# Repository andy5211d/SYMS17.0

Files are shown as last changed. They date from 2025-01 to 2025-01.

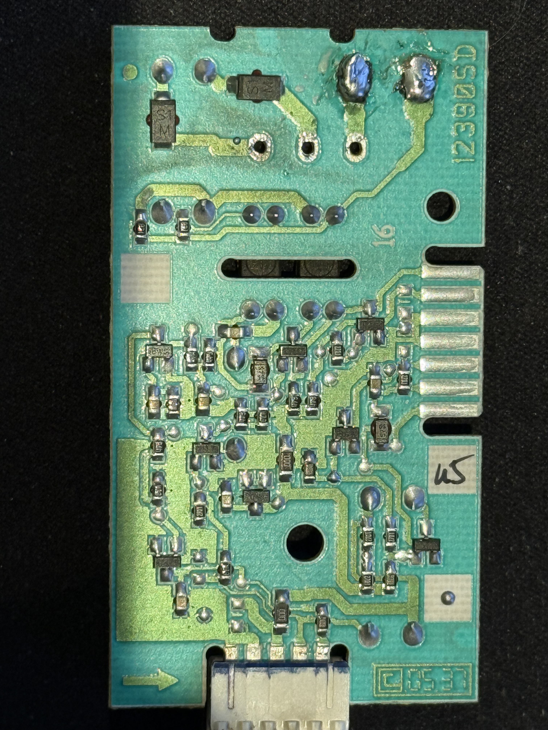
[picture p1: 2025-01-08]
pictures/230V Controls Track Side.JPG

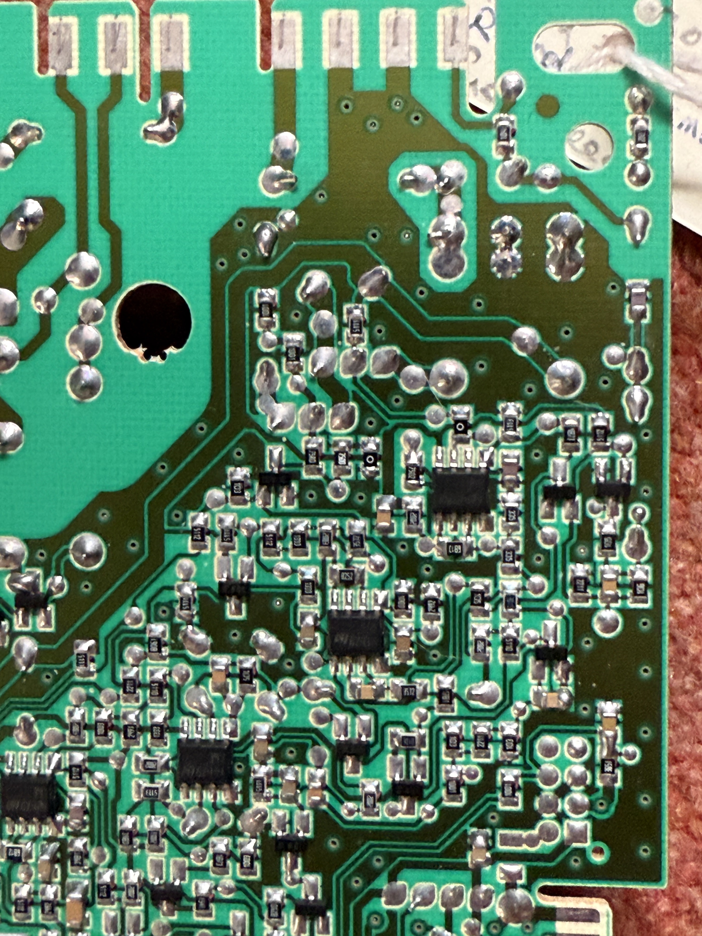
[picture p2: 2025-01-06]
pictures/IMG_2305.JPG

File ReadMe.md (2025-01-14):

The SYMS17.0 Control PCB (2000802731) used in a number of central heating and combi boilers.  This board has voltages that WILL KILL YOU if you touch the HV DC side.  

Included are details of some capacitors that may require changing if the board is faulty.  I change the five main capacitors as a matter of course.  A fault in the HV side (blown switcher) will often take out tracks and the through-hole plating. Usually not worth trying to repair.  Also included are some circuit details and relevant voltages around the PCB.  

Check your board as this is just my guess as to the details and circuit snippets!  

This is an unregulated SMPS, in that there is NO feedback between the secondary voltages and the switcher drive.  The main LV DC is around 40V with the boiler quiescent, (note the smoothing capacitors for this are 35V working!), and during operation drops to around 30V dependent upon fan speed.  The second LV DC is around 12V dropping to 9V dependent upon fan speed.  Two other voltages, 18V and 5V are used and these are from regulators and thus stable irrespective of the fan speed.  There are probably other derived voltages and thus regulators.  The opto coupler, U102, provides the controlling micro with the AC input (and perhaps HV DC value), or at least that's my assumption from tracing tracks on the board!

I have noticed at least three versions of the board (see number at the bottom left corner). As best I can tell variations are around the regulator U503, some boards seem to omit this and later boards this regulator has been designed out.

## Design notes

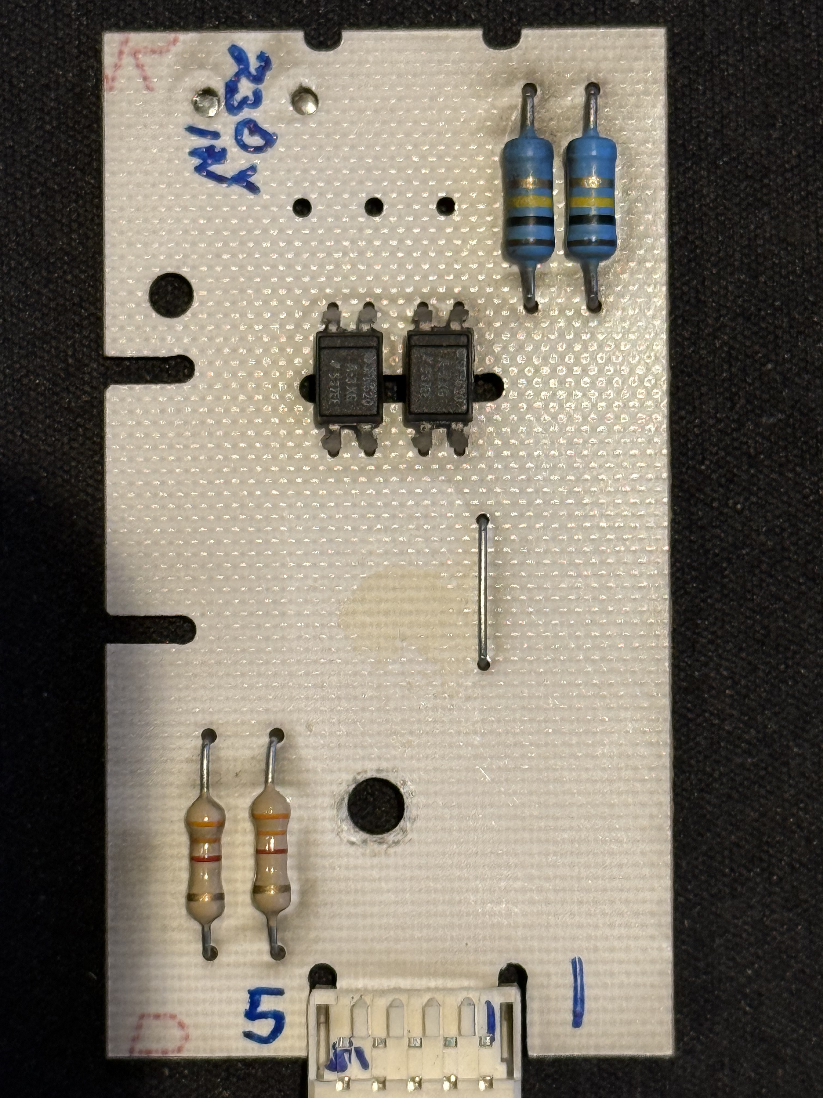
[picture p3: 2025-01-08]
pictures/230V Controls Comp Side.JPG

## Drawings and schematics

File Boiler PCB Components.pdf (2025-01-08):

# Glow Worm cxi, hxi & sxi PCB - Components

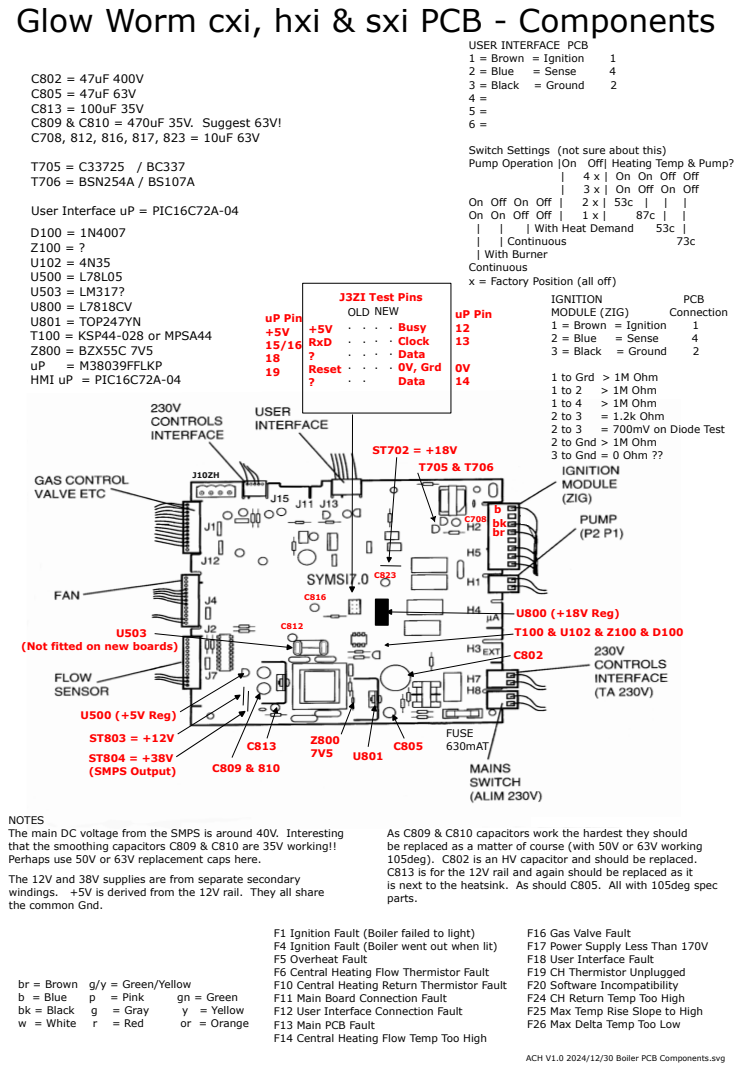
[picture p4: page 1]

Switch Settings (not sure about this)
Pump Operation |On Off| Heating Temp & Pump?

With Burner
Continuous
x = Factory Position (all off)

(Not fitted on new boards)

NOTES
The main DC voltage from the SMPS is around 40V. Interesting
that the smoothing capacitors C809 & C810 are 35V working!!
Perhaps use 50V or 63V replacement caps here.
The 12V and 38V supplies are from separate secondary
windings. +5V is derived from the 12V rail. They all share
the common Gnd.

As C809 & C810 capacitors work the hardest they should
be replaced as a matter of course (with 50V or 63V working
105deg). C802 is an HV capacitor and should be replaced.
C813 is for the 12V rail and again should be replaced as it
is next to the heatsink. As should C805. All with 105deg spec
parts.

F1 Ignition Fault (Boiler failed to light)
F4 Ignition Fault (Boiler went out when lit)
F5 Overheat Fault
F6 Central Heating Flow Thermistor Fault
F10 Central Heating Return Thermistor Fault
F11 Main Board Connection Fault
F12 User Interface Connection Fault
F13 Main PCB Fault
F14 Central Heating Flow Temp Too High

F16 Gas Valve Fault
F17 Power Supply Less Than 170V
F18 User Interface Fault
F19 CH Thermistor Unplugged
F20 Software Incompatibility
F24 CH Return Temp Too High
F25 Max Temp Rise Slope to High
F26 Max Delta Temp Too Low

br = Brown g/y = Green/Yellow

ACH V1.0 2024/12/30 Boiler PCB Components.svg

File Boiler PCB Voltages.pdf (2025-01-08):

# Glow Worm cxi, hxi & sxi PCB - Voltages

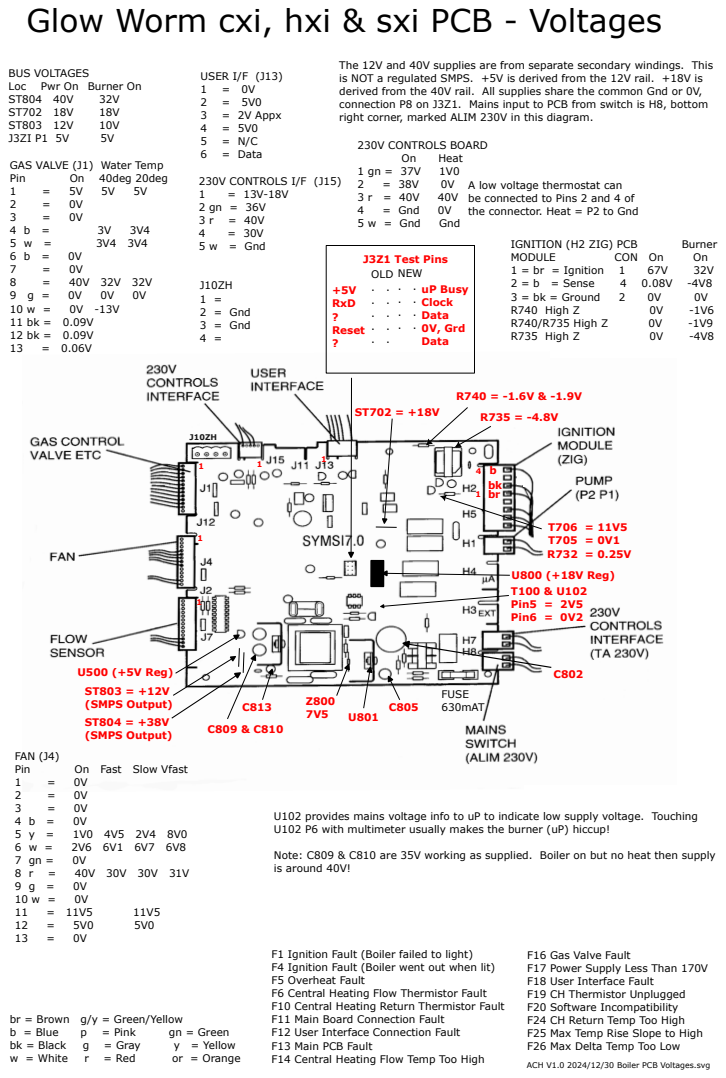
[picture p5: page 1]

The 12V and 40V supplies are from separate secondary windings. This
is NOT a regulated SMPS. +5V is derived from the 12V rail. +18V is
derived from the 40V rail. All supplies share the common Gnd or 0V,
connection P8 on J3Z1. Mains input to PCB from switch is H8, bottom
right corner, marked ALIM 230V in this diagram.

BUS VOLTAGES
Loc Pwr On Burner On

GAS VALVE (J1) Water Temp

A low voltage thermostat can
be connected to Pins 2 and 4 of
the connector. Heat = P2 to Gnd

U102 provides mains voltage info to uP to indicate low supply voltage. Touching
U102 P6 with multimeter usually makes the burner (uP) hiccup!

Note: C809 & C810 are 35V working as supplied. Boiler on but no heat then supply
is around 40V!

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

br = Brown g/y = Green/Yellow

ACH V1.0 2024/12/30 Boiler PCB Voltages.svg

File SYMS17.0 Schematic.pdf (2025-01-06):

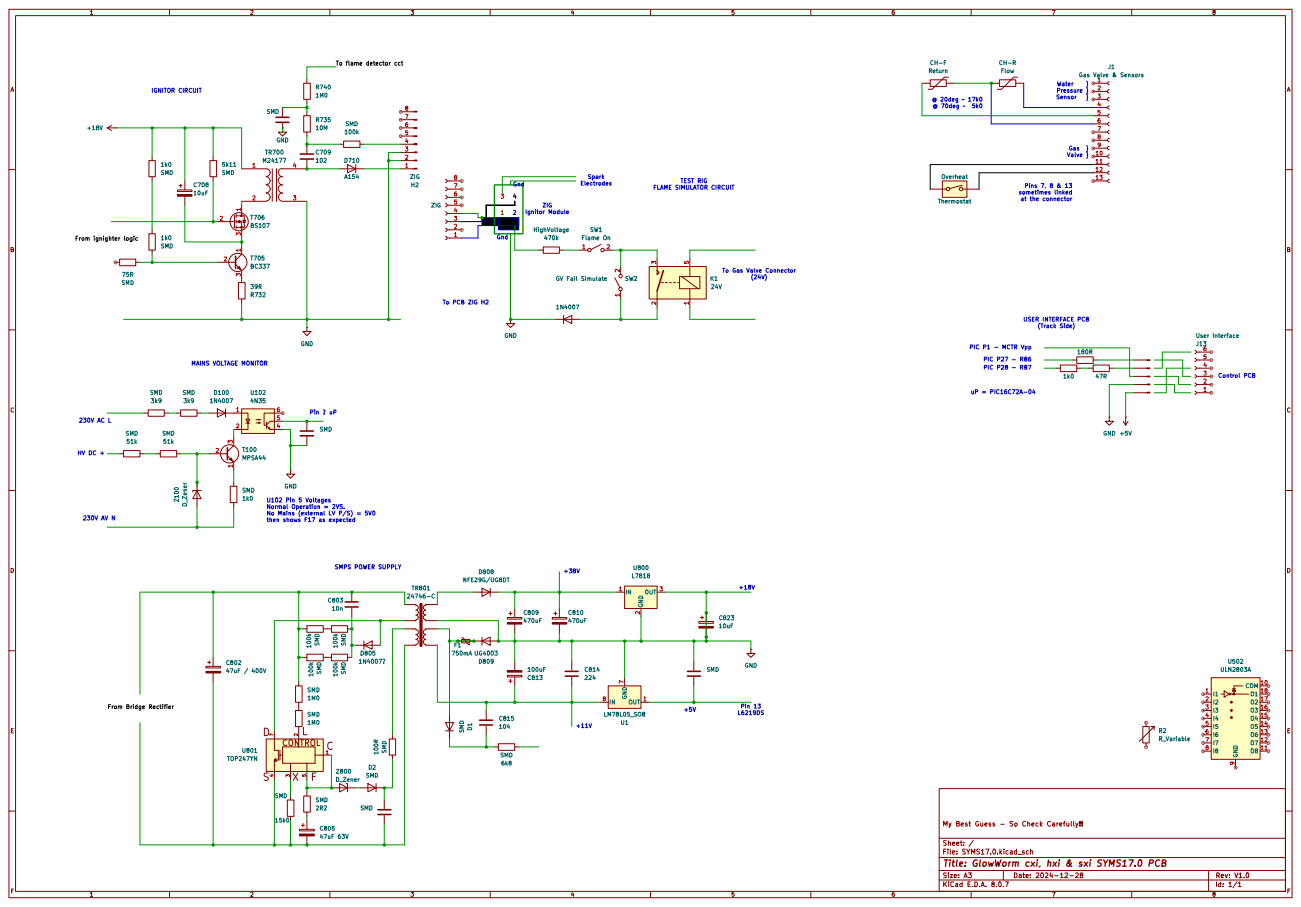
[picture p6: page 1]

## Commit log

2025-01-01 Files added and others updated
    PDF files now have content! KiCad files added
    [SYMS17.0.kicad_pcb, SYMS17.0.kicad_sch]
2025-01-06 Detail Added
    Further details added to schematic and layout diagrams.
